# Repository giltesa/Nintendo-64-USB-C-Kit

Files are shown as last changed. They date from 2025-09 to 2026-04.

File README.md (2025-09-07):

# Nintendo 64: USB-C Kit

The **Nintendo 64: USB-C Kit** is a board that allows to replace the original power supply unit for a modern and standard USB-C.

**If your original power supply unit is too old or damaged** and you need a new one, or **if you would like to power up your Nintendo 64 with a standard USB-C PD charger**, such as the charger for your phone, or laptop, you can do so with this kit.

## HOW DOES IT WORK?

The **USB-C Power Delivery technology (USB-C PD)** allows for communication between the device and the charger, enabling the negotiation of the voltage to be supplied through the USB-C cable. In this case, the microchip included in this board is configured to request 9V, signaling to the charger that it requires 9V to operate. If the charger is compatible, it will supply the requested voltage. If it’s not compatible, nothing will happen, and the Nintendo 64 won’t be able to power on.

As is well known, the original power supply unit provides not only 9V but also a 3.3V output. The kit includes a buck converter to supply this, ensuring that all electrical functions are covered by the kit.

N64
N64
N64

## Would you like it?

[**Nintendo 64: USB-C Kit**](https://shop.giltesa.com/?p=2489)

## License

This project is licensed under a **Creative Commons** license:
**[Attribution-NonCommercial-ShareAlike 4.0 International (CC BY-NC-SA 4.0) ](https://creativecommons.org/licenses/by-nc-sa/4.0/)**

Check the [LICENSE.md](LICENSE.md) for more information.

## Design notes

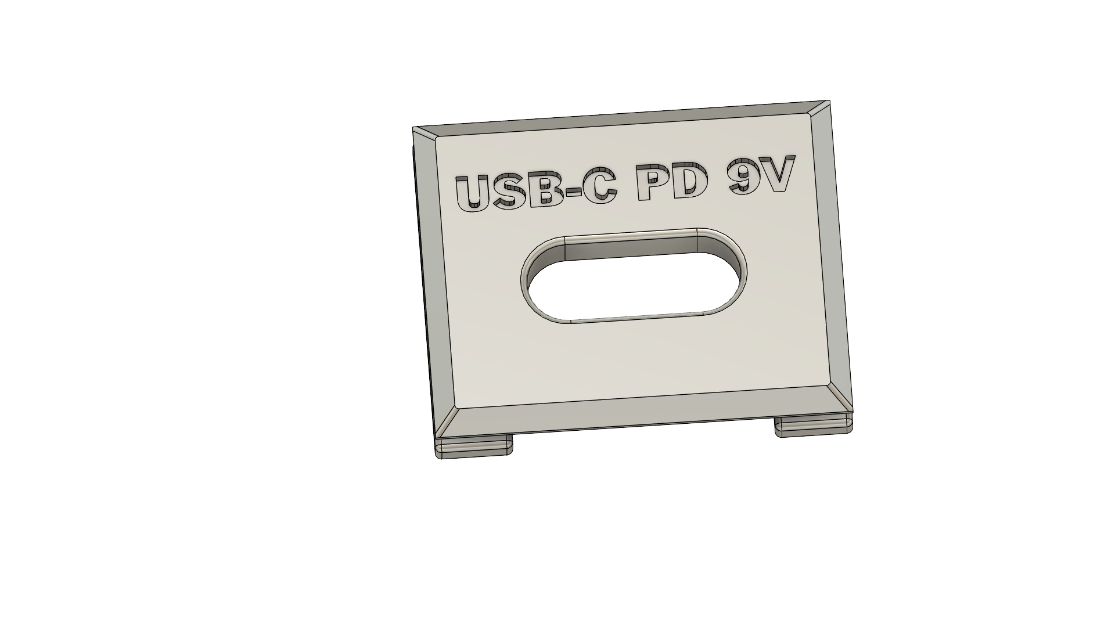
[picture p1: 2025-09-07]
2. Renders, 3D models/Cap/N64 v15.png

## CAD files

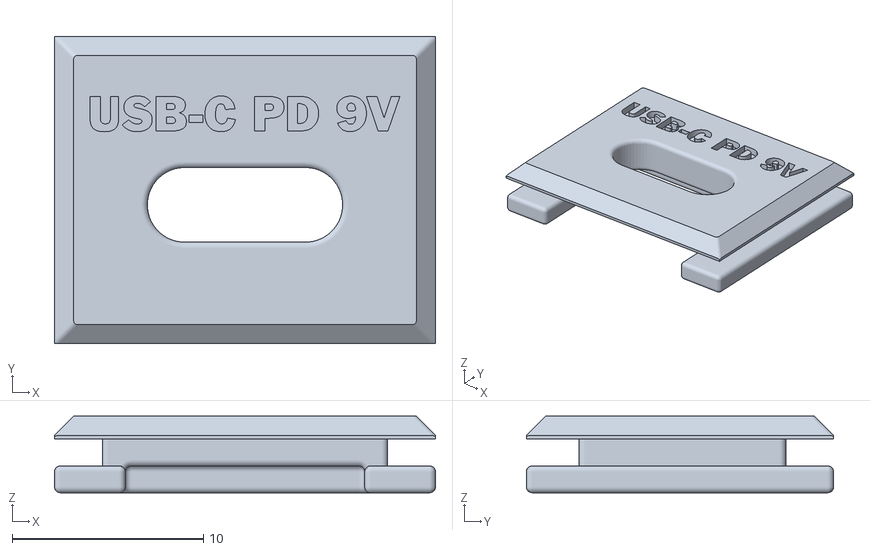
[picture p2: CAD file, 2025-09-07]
2. Renders, 3D models/Cap/N64 v15.stl
19.9 x 16.1 x 4.00

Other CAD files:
2. Renders, 3D models/Cap/N64 v15.f3d
2. Renders, 3D models/PCB v1.4.skp

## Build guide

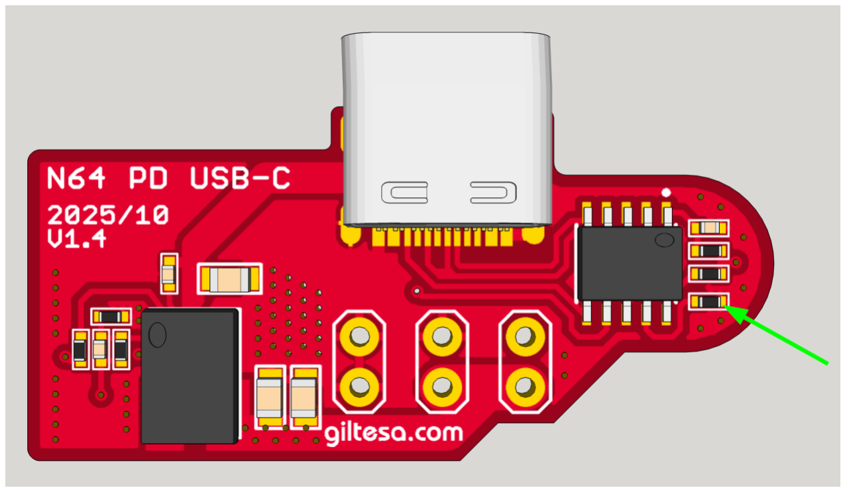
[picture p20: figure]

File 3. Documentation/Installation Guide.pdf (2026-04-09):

# USB-C KIT For

# Nintendo 64

PRODUCT

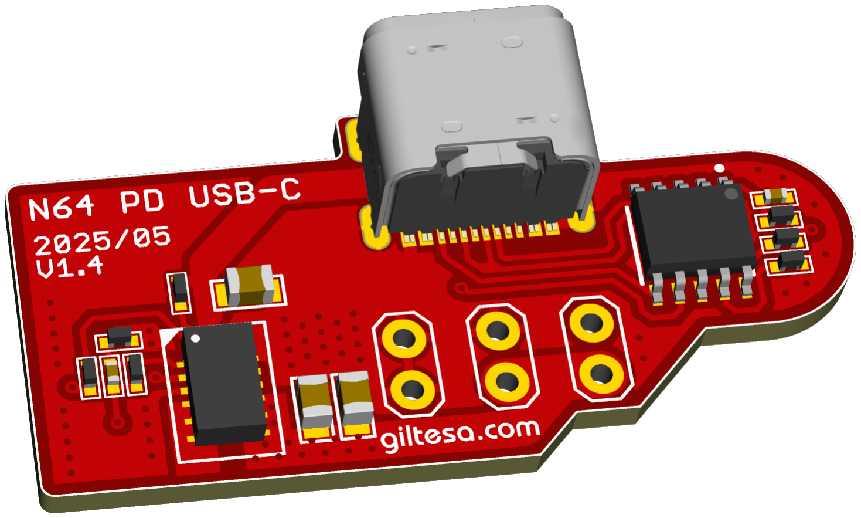
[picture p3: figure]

HTTPS://SHOP.GILTESA.COM/PRODUCT/NINTENDO-64-USB-C-KIT

# PLEASE READ THROUGH THESE INSTRUCTIONS

ENTIRELY BEFORE ATTEMPTING TO INSTALL.

# WARNING: IF YOU ARE NOT COMFORTABLE WITH SOLDERING, OR PERFORMING ANY STEP IN THIS

GUIDE, DO NOT PERFORM THE INSTALL YOURSELF.

# FIND SOMEONE WHO IS COMFORTABLE TO DO IT FOR

YOU.

INDEX

# Description

The Nintendo 64: USB-C Kit is a board that allows to replace the original power supply unit for a modern and standard USB-C.

If your original connector or power supply is too old or damaged and you need a new one, or if you would like to power your Nintendo 64 with a standard USB-C PD charger, such as the charger for your phone or laptop, you can do so with this kit.

# HOW DOES IT WORK?

The USB-C Power Delivery technology (USB-C PD) allows for communication between the device and the charger, enabling the negotiation of the voltage to be supplied through the USB-C cable. In this case, the microchip included on this board is configured to request 9V, signalling to the charger that it requires 9V to operate. If the charger is compatible, it will supply the requested voltage. If it’s not compatible, nothing will happen, and the Nintendo 64 won’t power on.

As is well known, the original power supply unit provides not only 12V but also a 3.3V output. The kit includes a buck converter to supply this, ensuring that all electrical functions are covered by the kit. (The 12V rail can also be powered with 9V, which is how this kit works, resulting in higher energy efficiency)

# FEATURES

- Exact shape for Nintendo 64.
- External power through USB-C.

# INCLUDED

- 1 USB-C board.
- 3 header pins of two pins.
- 1 Plastic cap for the USB-C board (black color)
- 1 Aluminium heatsink.

# Recommended / REQUIRED (NOT INCLUDED)

- 4.5mm gamebit and Phillips
screwdrivers.
- Tin soldering iron.
- Tin.
- Flux.
- Desoldering pump.
- Isopropyl alcohol.

# NOTES

This kit requires a special power supply that supports power delivery (PD) with an output of 9V and a minimum of 3A. Generally, laptop power supplies and some phone chargers can be used. If you don’t have any, take a look at the list of recommendations.

- Ikea SJÖSS 45W 12V 3A, (https://www.ikea.com/es/en/p/sjoss-45w-2-port-usb-charger-fast-charging-80574438/) 13€

You will also need a USB-C to USB-C cable for PD. If you don’t have one, these will work:

- Ikea SITTBRUNN USB-C to USB-C 1m (https://www.ikea.com/es/en/p/sittbrunn-usb-c-to-usb-c-blue-30546650/)
- Ikea LILLHULT USB-C to USB-C 1.5 m (https://www.ikea.com/es/en/p/lillhult-usb-c-to-usb-c-dark-grey-50527603/)

# Board details

This small board comes almost fully assembled, except for the connector that will link it to the console.

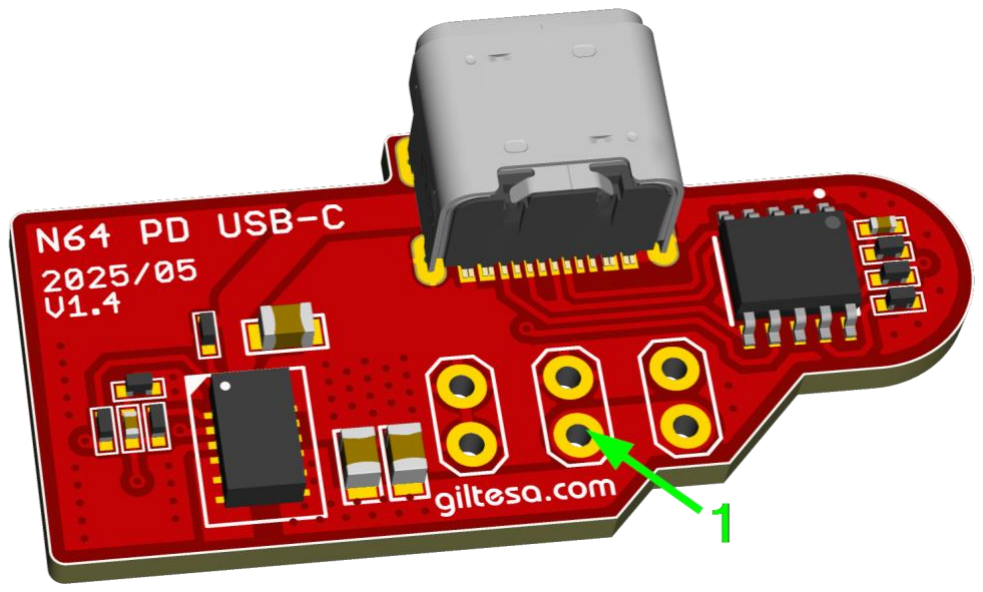
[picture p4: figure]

1. Pin connector for N64

# Test the board!

Before starting the installation, you should test the board. If it doesn’t work contact me for a replacement (https://shop.giltesa.com/refund-policy/) (all boards are fully tested, but they may damage during the shipping, we try to package them as better as possible), if it works, go ahead with the installation.

Connect the power from your USB charger to the USB-C connector on the board. Then, using a multimeter in voltage measurement mode, check for a 9V reading at these points:

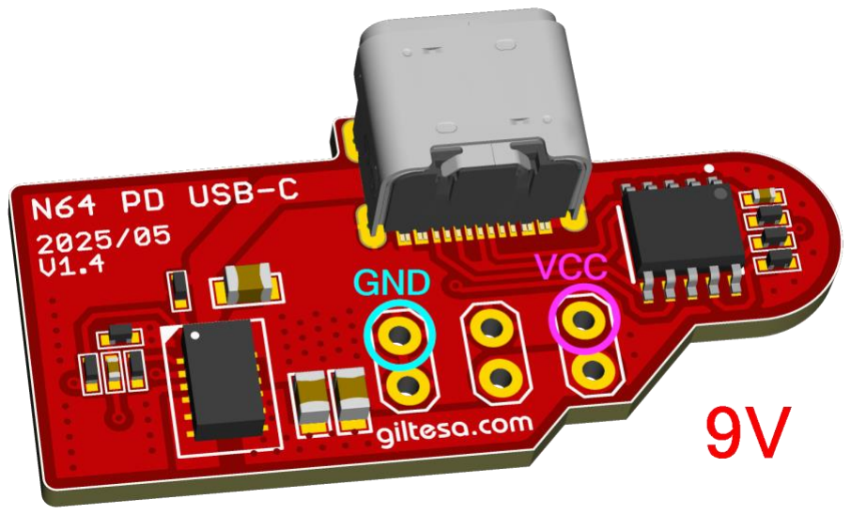
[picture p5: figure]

Next, check for a 3.3V reading at these points:

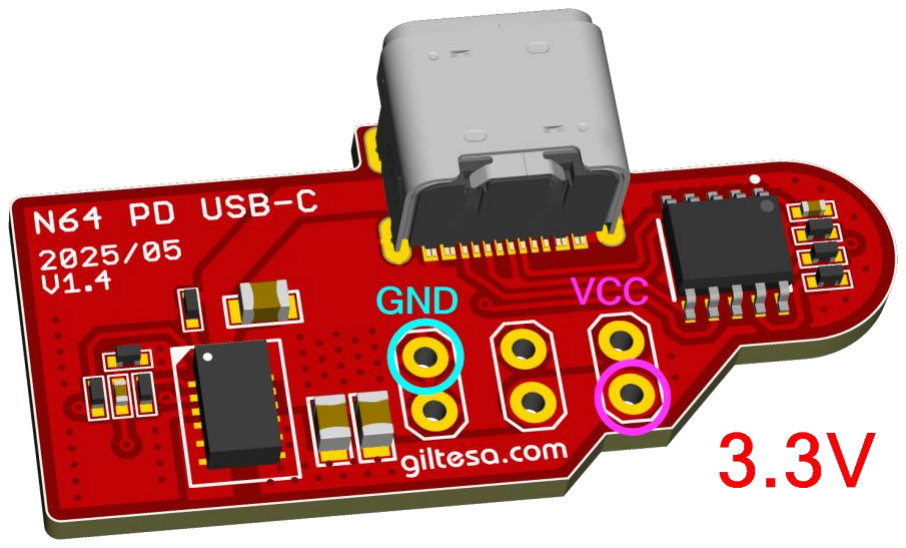
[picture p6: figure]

# INSTALLATION STEPS

Please, carefully read the following steps for a successful installation.

## Pre installation Steps

Before the installation, your Nintendo 64 may need some extra steps to have it ready for the kit.

1. Disassembly the NINTENDO 64

Nintendo products in general use two kind of screws. The first one called gamebit to close the shell, and the second one called phillips to hold the main board to the shell.

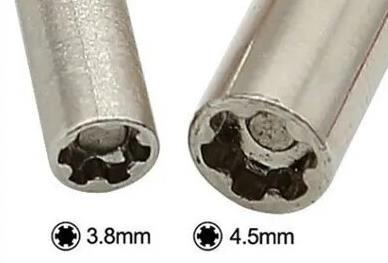
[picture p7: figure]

Gamebit screwdriver
Use the 4.5mm gamebit screwdriver to open the shell and remove the 6 gamebit screws.

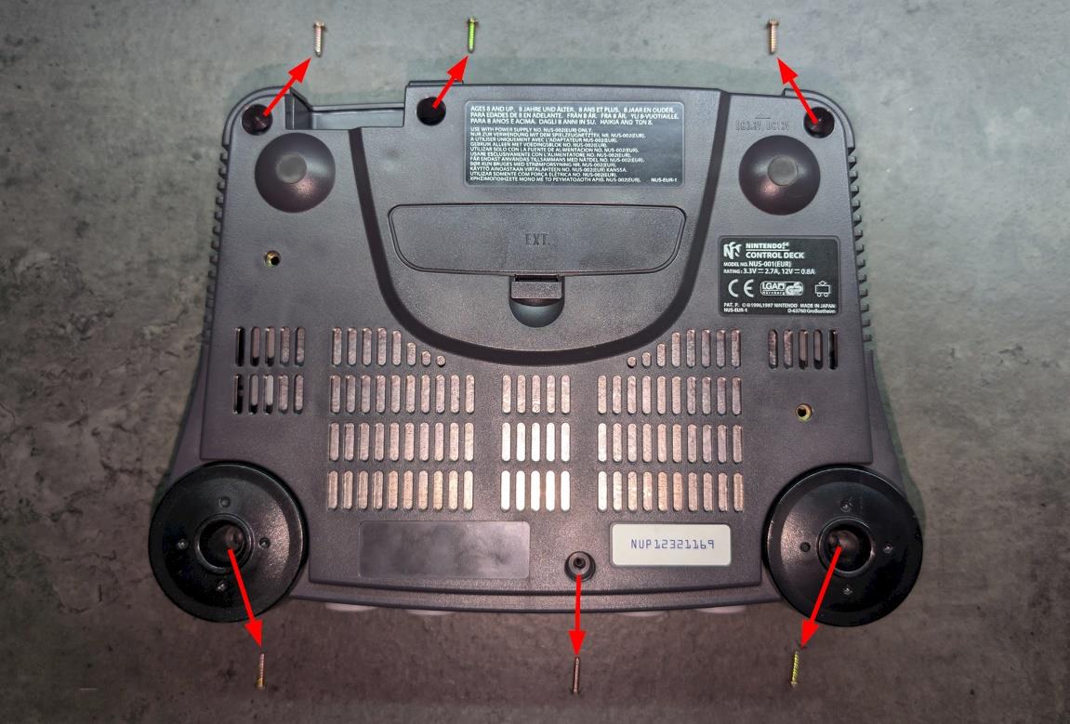
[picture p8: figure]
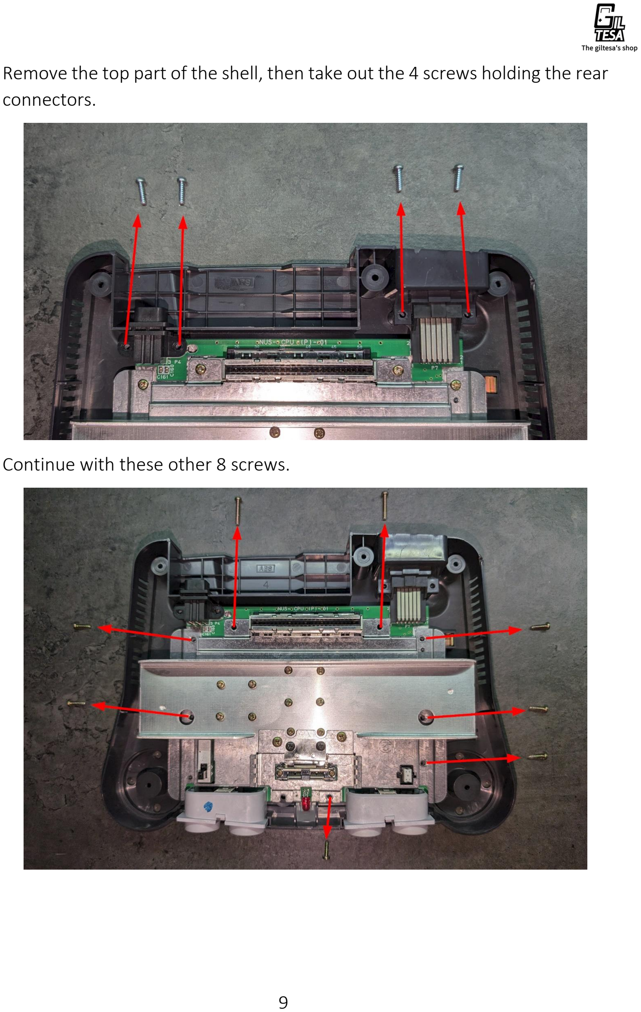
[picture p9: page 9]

Remove the top part of the shell, then take out the 4 screws holding the rear connectors.

Continue with these other 8 screws.

Finally, remove these two screws holding the memory expansion port.

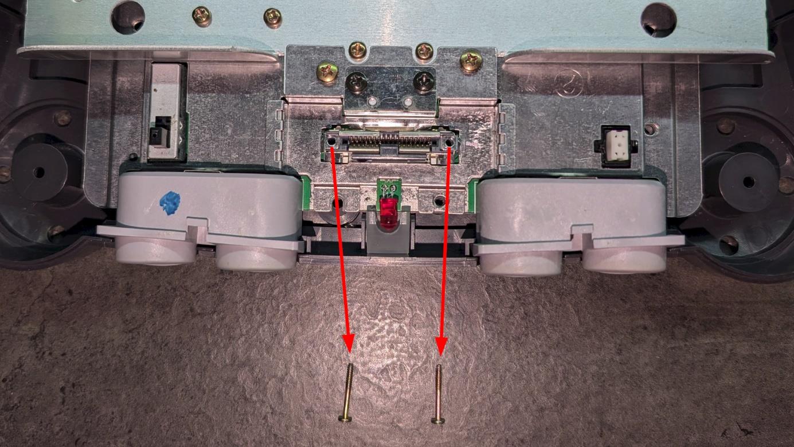
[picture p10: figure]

2. Remove unnecessary parts

The only part that needs to be removed is the power connector. Since all its pins are very close together, you can apply a solder ball to heat them all at the same time with the soldering iron. Once it’s hot enough, the connector will fall off on its own or with a little help.

After removing the connector, clean up the excess solder and wipe the board with alcohol.

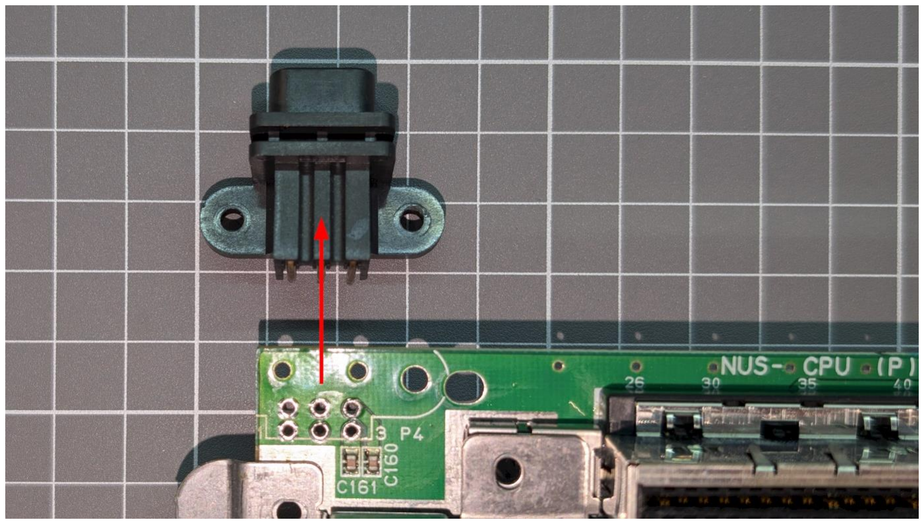
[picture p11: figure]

## installation Steps

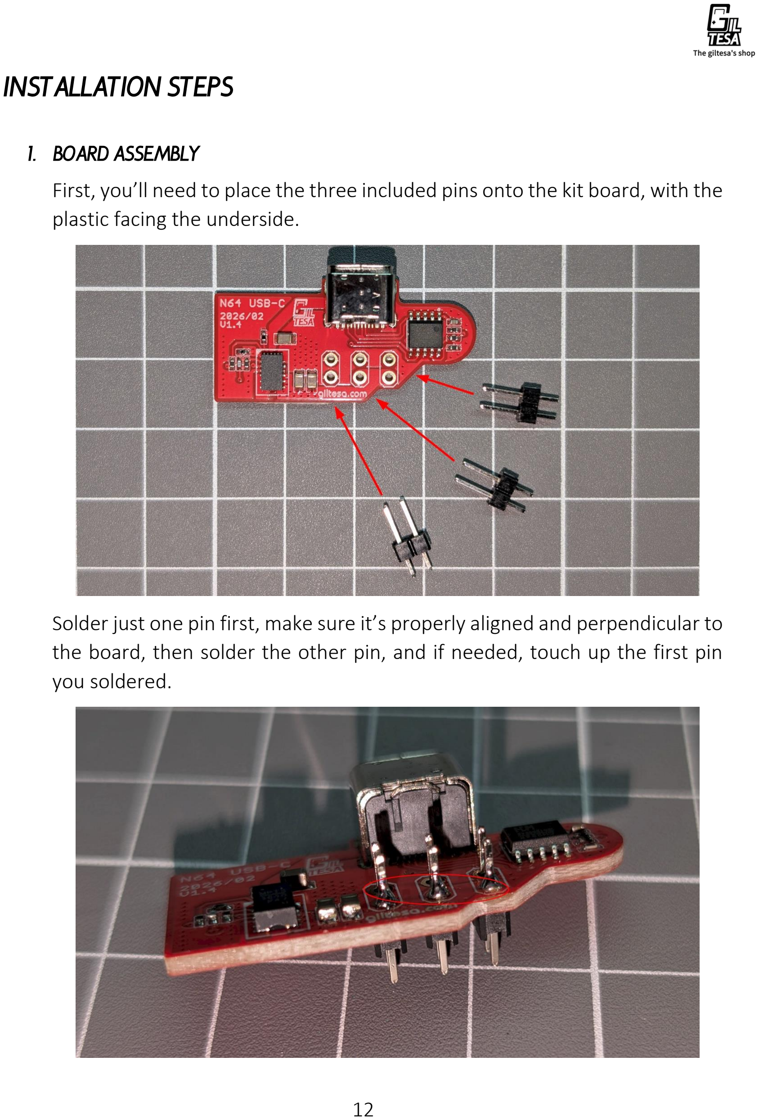
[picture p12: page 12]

1. Board assembly

First, you’ll need to place the three included pins onto the kit board, with the plastic facing the underside.

Solder just one pin first, make sure it’s properly aligned and perpendicular to the board, then solder the other pin, and if needed, touch up the first pin you soldered.

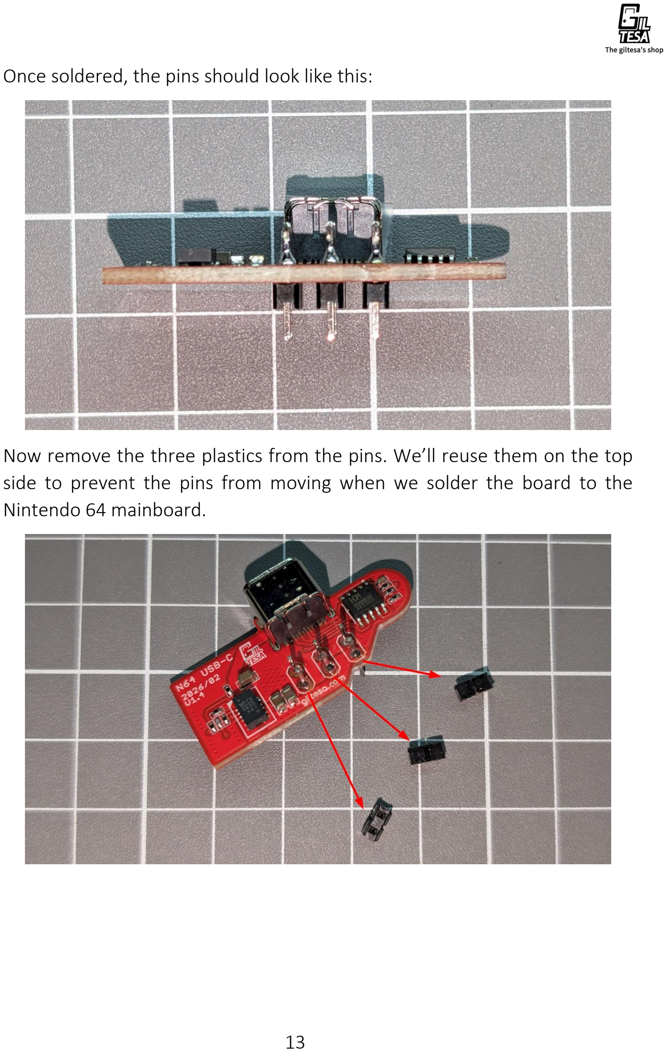
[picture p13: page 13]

Once soldered, the pins should look like this:

Now remove the three plastics from the pins. We’ll reuse them on the top side to prevent the pins from moving when we solder the board to the Nintendo 64 mainboard.

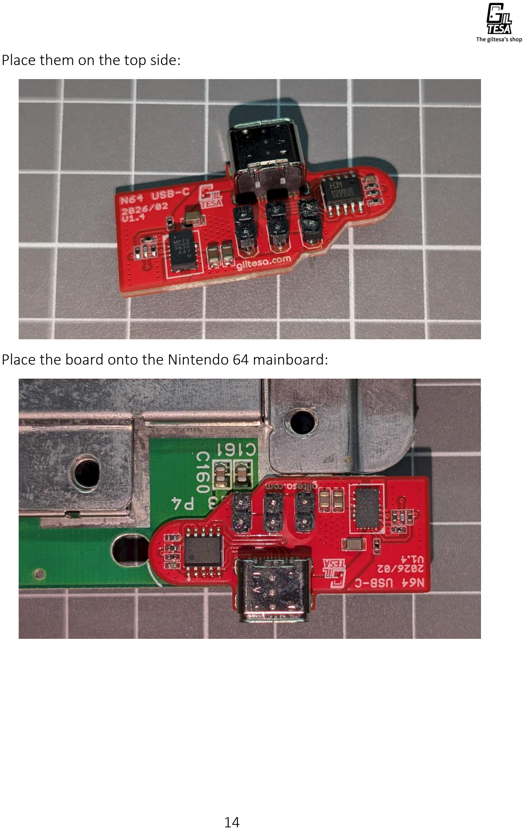
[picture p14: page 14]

Place them on the top side:

Place the board onto the Nintendo 64 mainboard:

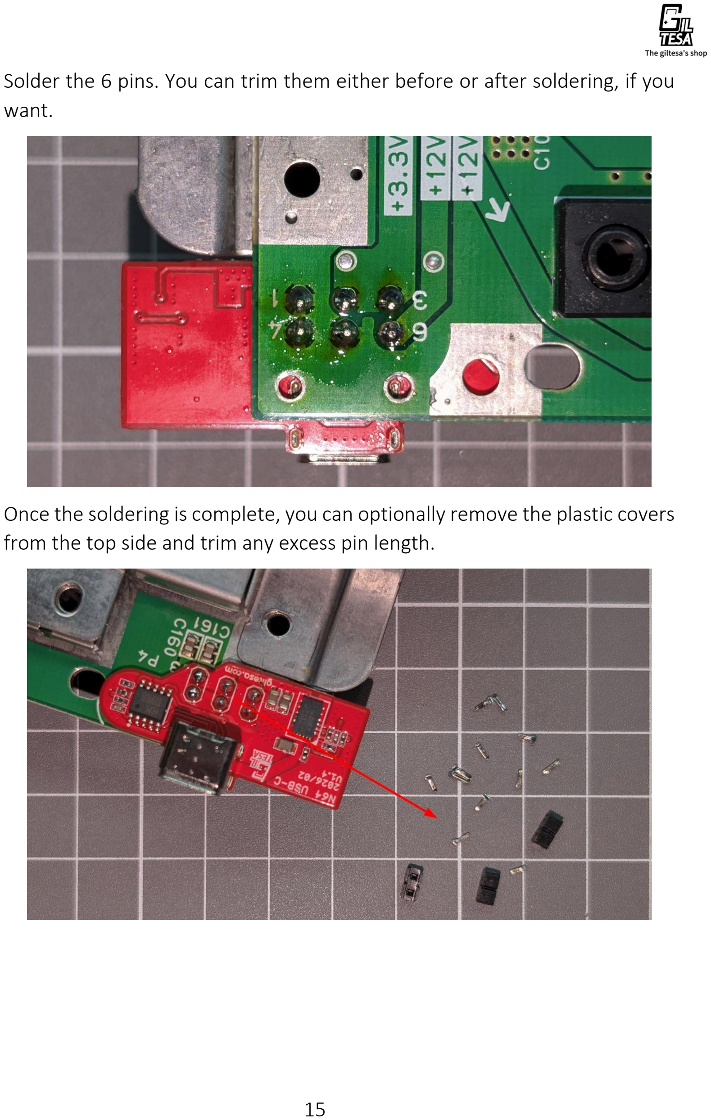
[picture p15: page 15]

Solder the 6 pins. You can trim them either before or after soldering, if you want.

Once the soldering is complete, you can optionally remove the plastic covers from the top side and trim any excess pin length.

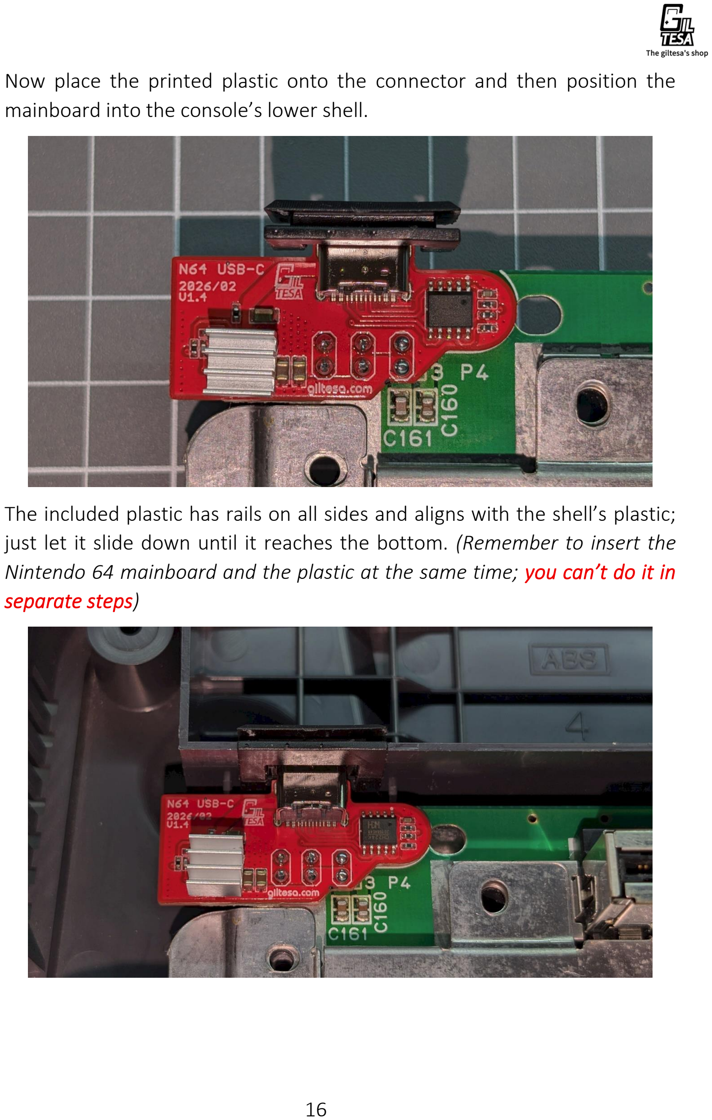
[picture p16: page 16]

Now place the printed plastic onto the connector and then position the mainboard into the console’s lower shell.

The included plastic has rails on all sides and aligns with the shell’s plastic; just let it slide down until it reaches the bottom. (Remember to insert the Nintendo 64 mainboard and the plastic at the same time; you can’t do it in separate steps)

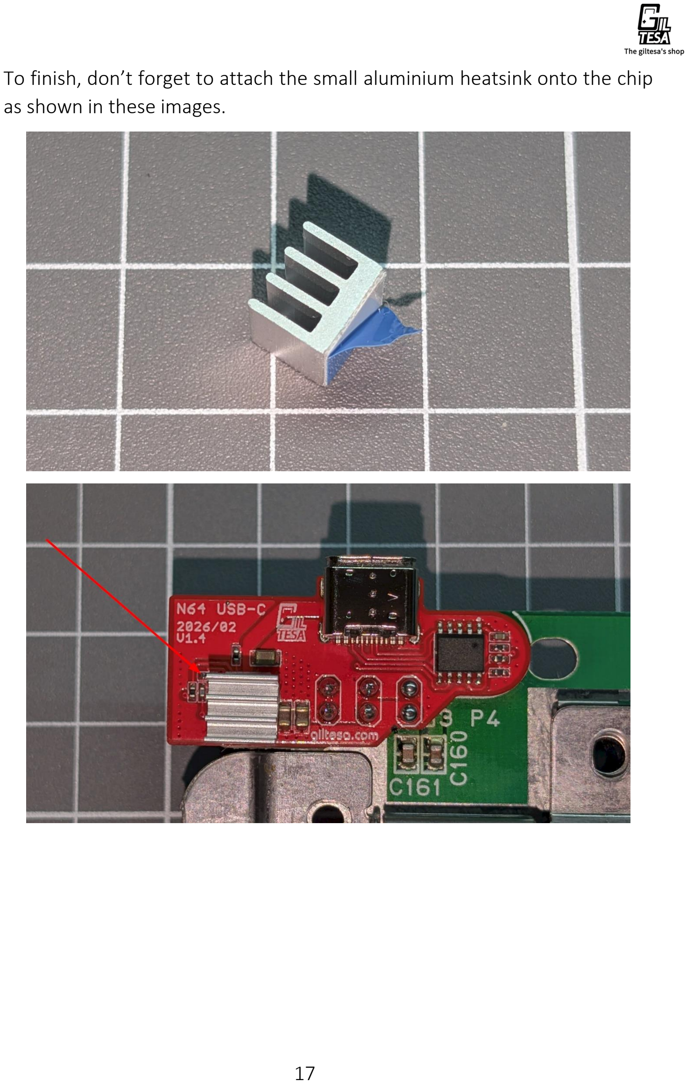
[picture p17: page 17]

To finish, don’t forget to attach the small aluminium heatsink onto the chip as shown in these images.

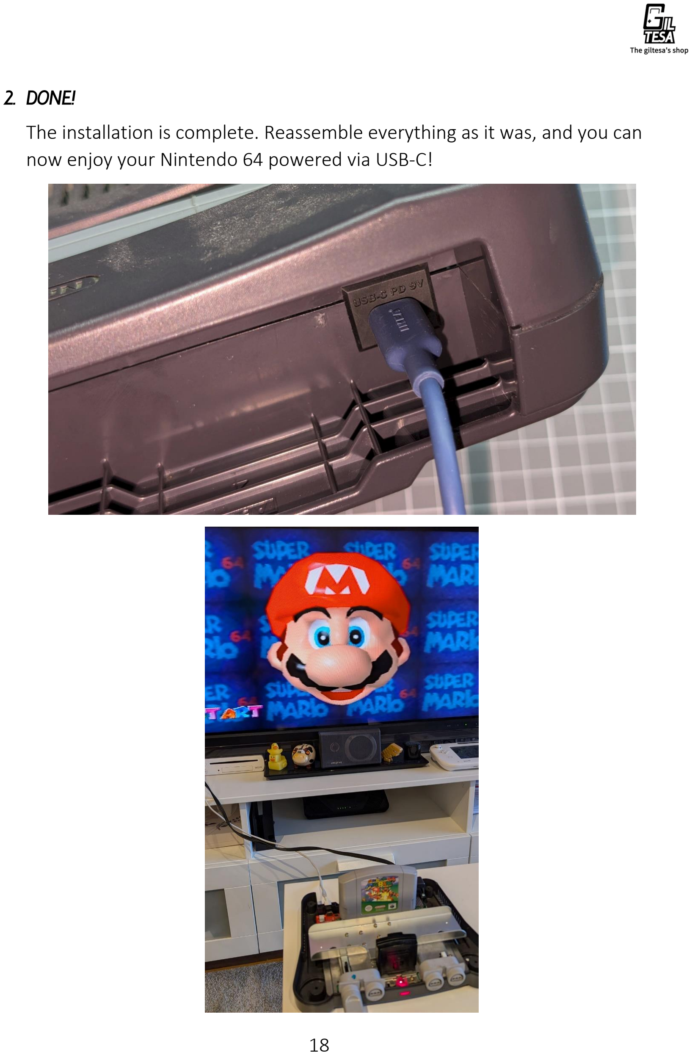
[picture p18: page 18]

2. Done!

The installation is complete. Reassemble everything as it was, and you can now enjoy your Nintendo 64 powered via USB-C!

# Frequently Asked Questions – FAQ

Is there a recommended power supply?
Any USB-C Power Delivery charger with a 9V 3A output is more than sufficient. We used the Ikea SJÖSS 45W (https://www.ikea.com/es/en/p/sjoss-45w-2-port-usb-charger-fast-charging-80574438/) (9V 3A) for all our tests.

The Nintendo 64 doesn't turn on.
Make sure you are using a USB-C power supply that can provide an output voltage of 9V and an electric current of at least 3A.

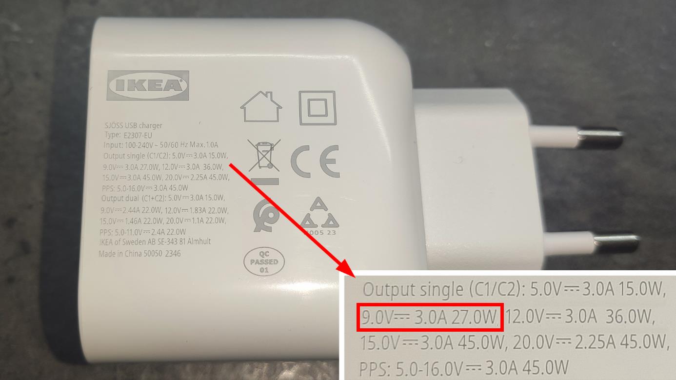
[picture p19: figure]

My power supply doesn’t have a 9V output.
Power Delivery chargers can supply a wide range of voltages: 5V, 9V, 12V, 15V, and 20V. However, they’re not required to support all of them, a charger might offer 5V, 9V, and 15V but not 12V or 20V.

That’s why it’s important to check whether your charger actually supports 9V output.

Can this kit be used with other mods?
Of course, as long as you use the appropriate power supply, 9V and 3A, then you can use any other mod or accessory you would normally use with the original power supply.

However, if you use any special mod that requires direct 12V power, you won’t be able to use it with this kit, as the maximum input voltage is 9V.

Enable compatibility for mods powered at 12V.
If you absolutely need the 12V input from the USB-C PD power supply, you can modify the board for this. It is not entirely easy due to the size of the components, but replacing this resistor with a 24K one, size 0402, will enable this function.

It is possible that with this change, and with high consumption on the 3.3V line, the current converter may heat up a little more.
